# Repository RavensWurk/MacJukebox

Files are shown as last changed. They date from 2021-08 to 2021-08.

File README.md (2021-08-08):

Banner
This project is an effort to develop a jukebox expansion board for vintage Macintosh computers. 
It is meant to plug into the standard modem port on all compacts (and later desktops), and provide
USB storage, audio output via a headphone jack, and a control interface for the computers. 

It will support MP3 files at most common bitrates and sample frequencies. The Macintosh, being
unable to actually decode modern music files or output high qualithy sound, will act as the command
and control interface for this external board. Playlists can be made, viewing artists/albums/songs, 
controlling mixer levels and volume, and the external board will handle all the decoding of the file,
outputting it to the audio jack.

This repo is organised in to two parts, the firmware for the board itself under "Board", and the Macintosh
software side under "MacApp".

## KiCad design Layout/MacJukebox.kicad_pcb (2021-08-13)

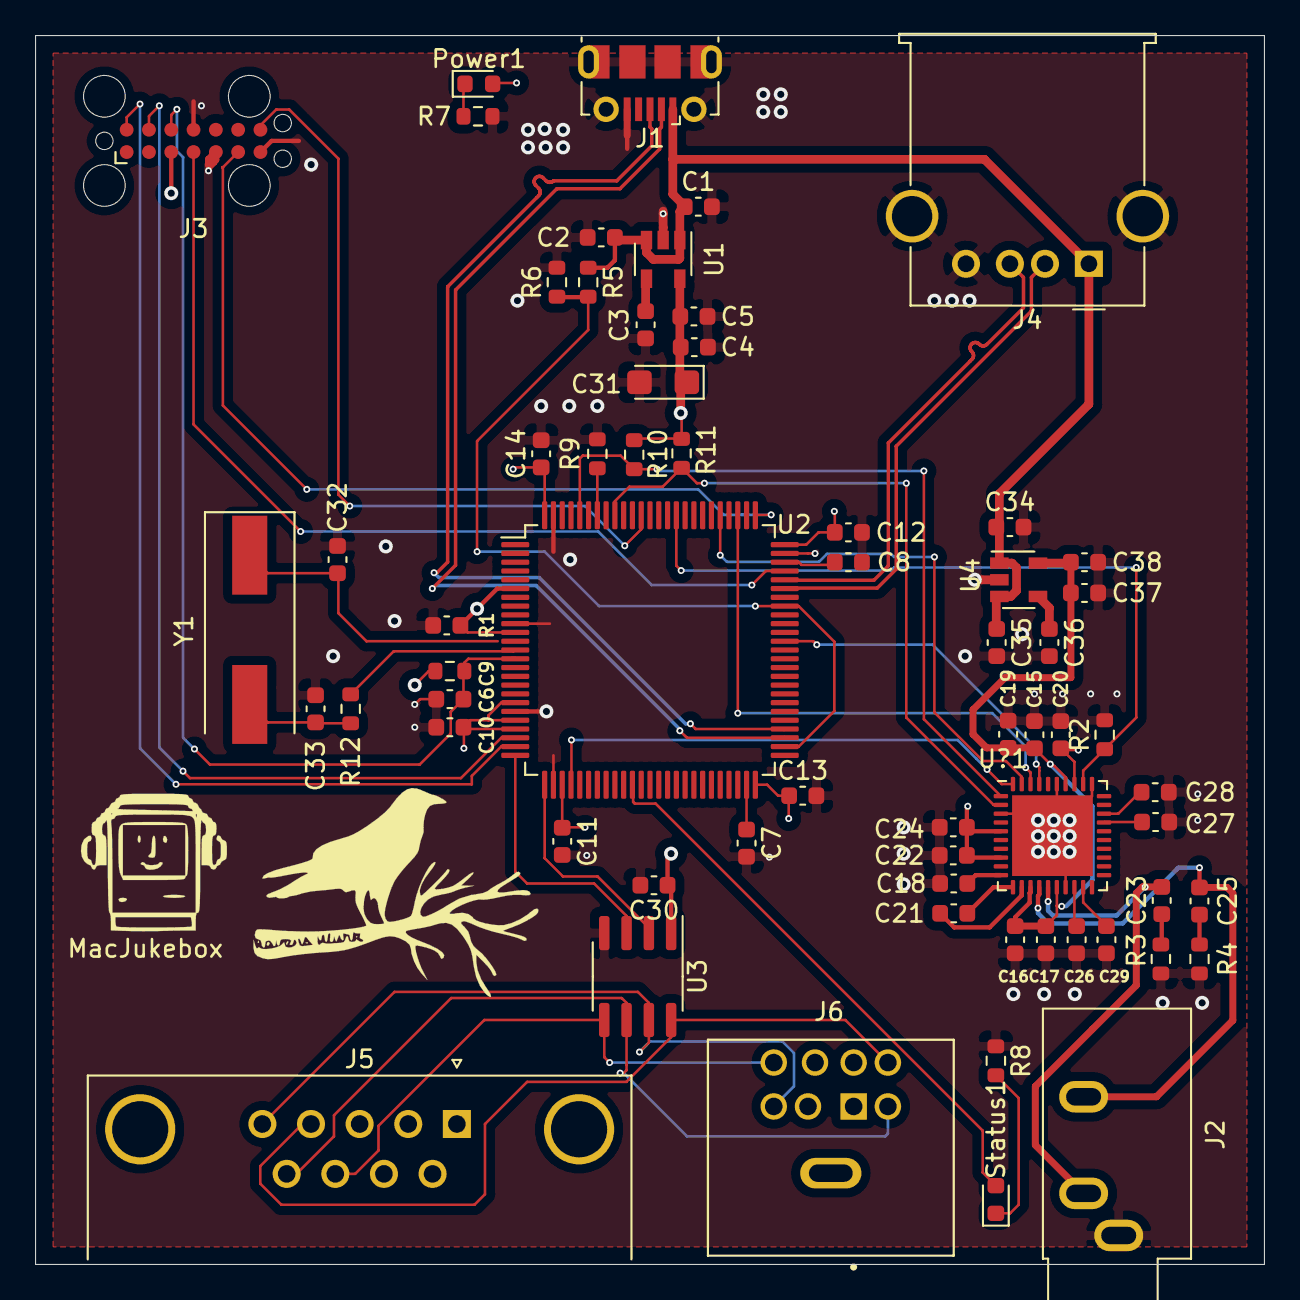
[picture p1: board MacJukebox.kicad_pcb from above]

Board: 4 copper layers, 70.0 x 70.0 mm, 64 parts (0 on the bottom side), 50 nets.

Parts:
C1, C4, C19, C22, C24, C30, C34, C37: 1uF; C_0603_1608Metric
C2, C5, C6, C9, C10, C11, C12, C13, C14, C15, C16, C17, C20, C35, C38: 100nF; C_0603_1608Metric
C3, C36: 10nF; C_0603_1608Metric
C7, C8: 2.2uF; C_0603_1608Metric
C18, C21, C26, C29: 1uF (X7R); C_0603_1608Metric
C23, C25: 22nF; C_0603_1608Metric
C27, C28: 150pF (C0G); C_0603_1608Metric
C31: 10uF; CP_EIA-3216-18_Kemet-A
C32, C33: 18pF; C_0603_1608Metric
J1: USB_B_Micro; USB_Micro-B_Molex-105017-0001
J2: AudioJack3; Jack_3.5mm_CUI_SJ1-3533NG_Horizontal
J3: Conn_ST_STDC14; Tag-Connect_TC2070-IDC-FP_2x07_P1.27mm_Vertical
J4: USB_A; USB_A_Molex_67643_Horizontal
J5: Mac 128/512; DSUB-9_Female_Horizontal_P2.77x2.84mm_EdgePinOffset4.94mm_H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
J6: Mini-DIN-8; CUI_MD-80S
Power1: RED LED; LED_0603_1608Metric
R1: 100K; R_0603_1608Metric
R2, R9: 10K; R_0603_1608Metric
R3, R4: 51; R_0603_1608Metric
R5: 1K; R_0603_1608Metric
R6: 2.4K; R_0603_1608Metric
R7, R8: 200; R_0603_1608Metric
R10, R11: 4.7K; R_0603_1608Metric
R12: 1.1K; R_0603_1608Metric
Status1: GREEN LED; LED_0603_1608Metric
U1: LD3985M33R_SOT23; SOT-23-5
U2: STM32F407VGTx; LQFP-100_14x14mm_P0.5mm
U3: MAX3488; SOIC-8_3.9x4.9mm_P1.27mm
U4: LD3985M25R_SOT23; SOT-23-5
U?1: CS43L22; QFN-40-1EP_6x6mm_P0.5mm_EP4.6x4.6mm
Y1: Crystal; Crystal_SMD_HC49-SD

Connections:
+2V5: C15.1, C16.1, C17.1, C19.1, C37.1, C38.1, U4.5, U?1.13, U?1.16, U?1.34
+3V3: C4.1, C5.1, C9.1, C10.1, C11.1, C12.1, C13.1, C14.1, C20.1, C22.1, C24.1, C30.1, C31.1, J3.3, Power1.2, R1.1, R10.1, R11.1, U1.5, U2.6, U2.11, U2.19, U2.21, U2.22, U2.28, U2.50, U2.75, U2.100, U3.1, U?1.5, U?1.8, U?1.33
+5V: C1.1, C2.1, C34.1, C35.1, J1.1, J4.1, R5.1, U1.1, U1.3, U4.1, U4.3
DI: U2.25, U3.3
GND: C1.2, C2.2, C3.2, C4.2, C5.2, C6.2, C7.2, C8.2, C9.2, C10.2, C11.2, C12.2, C13.2, C14.2, C15.2, C16.2, C17.2, C18.2, C19.2, C20.2, C22.2, C24.2, C26.2, C27.2, C28.2, C29.2, C30.2, C31.2, C32.1, C33.1, C34.2, C35.2, C36.2, C37.2, C38.2, J1.5, J1.6, J2.S, J3.5, J3.7, J3.11, J4.4, J4.5, R2.2, R3.1, R4.1, R6.2, R7.2, R8.1, R9.1, U1.2, U2.10, U2.20, U2.27, U2.74, U2.99, U3.4, U4.2, U?1.3, U?1.17, U?1.31, U?1.35, U?1.41
unnamed: C3.1, U1.4
unnamed: C7.1, U2.49
unnamed: C8.1, U2.73
unnamed: C18.1, U?1.10
unnamed: C21.1, U?1.11
unnamed: C21.2, U?1.12
unnamed: C23.1, R3.2
unnamed: C23.2, J2.T, U?1.15
unnamed: C25.1, R4.2
unnamed: C25.2, J2.R, U?1.14
unnamed: C26.1, U?1.18
unnamed: C27.1, U?1.27
unnamed: C28.1, U?1.28
unnamed: C29.1, U?1.19
unnamed: C33.2, R12.1, Y1.2
unnamed: C36.1, U4.4
unnamed: Power1.1, R7.1
unnamed: R8.2, Status1.1
unnamed: R9.2, U2.94
PA4: U2.29, U?1.40
PB6: R11.2, U2.92, U?1.2
PB9: R10.2, U2.96, U?1.1
PC7: U2.64, U?1.37
PC10: U2.78, U?1.38
PC12: U2.80, U?1.39
PD4: R2.1, U2.85, U?1.32
PH0: C32.2, U2.12, Y1.1
PH1: R12.2, U2.13
RO: U2.26, U3.2
RS422_RX+: J5.4, J6.6, U3.8
RS422_RX-: J5.5, J6.3, U3.7
RS422_TX+: J5.8, J6.8, U3.5
RS422_TX-: J5.9, J6.5, U3.6
RST: C6.1, J3.12, R1.2, U2.14
STATUS_LED: Status1.2, U2.36
SWCLK: J3.6, U2.76
SWDIO: J3.4, U2.72
SWO: J3.8, U2.89
USB_COMPUTER_D+: J1.3, U2.54
USB_COMPUTER_D-: J1.2, U2.53
USB_STORAGE_D+: J4.3, U2.71
USB_STORAGE_D-: J4.2, U2.70
VBUS_SENSE: R5.2, R6.1, U2.52, U2.68
VCP_RX: J3.13, U2.23
VCP_TX: J3.14, U2.24

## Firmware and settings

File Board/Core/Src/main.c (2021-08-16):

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
/* Includes ------------------------------------------------------------------*/
#include "main.h"
#include "cmsis_os.h"
#include "fatfs.h"
#include "usb_host.h"

/* USER CODE BEGIN Includes */
#include "codec.h"
#include "mp3player.h"
#include "uart_interface.h"
#include "pb_encode.h"
#include "parsers/filelist.pb.h"

/* USER CODE END Includes */

typedef StaticTask_t osStaticThreadDef_t;
I2C_HandleTypeDef hi2c1;

I2S_HandleTypeDef hi2s3;
DMA_HandleTypeDef hdma_spi3_tx;

SPI_HandleTypeDef hspi1;

UART_HandleTypeDef huart2;

/* Definitions for defaultTask */
osThreadId_t defaultTaskHandle;
uint32_t defaultTaskBuffer[ 1024 ];
osStaticThreadDef_t defaultTaskControlBlock;
const osThreadAttr_t defaultTask_attributes = {
  .name = "defaultTask",
  .stack_mem = &defaultTaskBuffer[0],
  .stack_size = sizeof(defaultTaskBuffer),
  .cb_mem = &defaultTaskControlBlock,
  .cb_size = sizeof(defaultTaskControlBlock),
  .priority = (osPriority_t) osPriorityNormal,
};
void SystemClock_Config(void);
static void MX_GPIO_Init(void);
static void MX_DMA_Init(void);
static void MX_I2C1_Init(void);
static void MX_I2S3_Init(void);
static void MX_SPI1_Init(void);
static void MX_USART2_UART_Init(void);
void StartDefaultTask(void *argument);

/* USER CODE BEGIN PFP */
bool writeListingToUART(pb_ostream_t *stream, const uint8_t *buf, size_t count);
/* USER CODE END PFP */

/**
  * @brief  The application entry point.
  * @retval int
  */
int main(void)
{
  /* MCU Configuration--------------------------------------------------------*/

  /* Reset of all peripherals, Initializes the Flash interface and the Systick. */
  HAL_Init();

  /* Configure the system clock */
  SystemClock_Config();

  /* Initialize all configured peripherals */
  MX_GPIO_Init();
  MX_DMA_Init();
  MX_I2C1_Init();
  MX_I2S3_Init();
  MX_SPI1_Init();
  MX_FATFS_Init();
  MX_USART2_UART_Init();
  /* Init scheduler */
  osKernelInitialize();

  /* USER CODE BEGIN RTOS_MUTEX */
  /* add mutexes, ... */
  /* USER CODE END RTOS_MUTEX */

  /* USER CODE BEGIN RTOS_SEMAPHORES */
  /* add semaphores, ... */
  /* USER CODE END RTOS_SEMAPHORES */

  /* USER CODE BEGIN RTOS_TIMERS */
  /* start timers, add new ones, ... */
  /* USER CODE END RTOS_TIMERS */

  /* USER CODE BEGIN RTOS_QUEUES */
  /* add queues, ... */
  /* USER CODE END RTOS_QUEUES */

  /* Create the thread(s) */
  /* creation of defaultTask */
  defaultTaskHandle = osThreadNew(StartDefaultTask, NULL, &defaultTask_attributes);

  /* USER CODE BEGIN RTOS_THREADS */
  /* add threads, ... */
  /* USER CODE END RTOS_THREADS */

  /* USER CODE BEGIN RTOS_EVENTS */
  /* add events, ... */
  /* USER CODE END RTOS_EVENTS */

  /* Start scheduler */
  osKernelStart();

  /* We should never get here as control is now taken by the scheduler */
  /* Infinite loop */
  /* USER CODE BEGIN WHILE */
  while (1)
  {
    /* USER CODE END WHILE */

    /* USER CODE BEGIN 3 */
  }
  /* USER CODE END 3 */
}

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
/* USER CODE BEGIN 4 */
struct MP3Player player;

bool encodeFileListing(pb_ostream_t *ostream, const pb_field_t *field, void * const *arg)
{
    const char *targetDir = (const char*)*arg;

    FILINFO info;
    DIR dir;
    FRESULT result = f_findfirst(&dir, &info, targetDir, "*.mp3");

    while (result == FR_OK && info.fname[0]) {
        FileListing_File file = {
            .Size = info.fsize
        };
        strcpy(file.Name, info.fname);

        pb_encode_tag_for_field(ostream, field);
        pb_encode_submessage(ostream, FileListing_File_fields, &file);
        result = f_findnext(&dir, &info);
    }

    f_closedir(&dir);

    return true;
}

void listFiles(void)
{
    pb_ostream_t uartStream = {
        writeListingToUART,
        NULL,
        SIZE_MAX,
        0
    };

    FileListing listing = FileListing_init_zero;
    listing.files.funcs.encode = encodeFileListing;
    listing.files.arg = "/";
    pb_encode(&uartStream, FileListing_fields, &listing);
}

bool writeListingToUART(pb_ostream_t *stream, const uint8_t *buf, size_t count)
{
    UartInterface_Write(&huart2, buf, count);

    return true;
}

void onCommand(Command* command)
{
    switch (command->id) {
        case Command_ID_PLAY_FILE:
            MP3PlayerPlayFile(&player, (const char*)command->data.bytes);
            break;
        case Command_ID_PAUSE:
            MP3PlayerPause(&player);
            break;
        case Command_ID_LIST_FILES:
            osThreadFlagsSet (defaultTaskHandle, 2);
            break;
        default:
            break;
    }
}

/* USER CODE END 4 */

/* USER CODE BEGIN Header_StartDefaultTask */
/**
  * @brief  Function implementing the defaultTask thread.
  * @param  argument: Not used
  * @retval None
  */
/* USER CODE END Header_StartDefaultTask */
void StartDefaultTask(void *argument)
{
  /* init code for USB_HOST */
  MX_USB_HOST_Init();
  /* USER CODE BEGIN 5 */
  struct Codec codec;

  codec.i2c = &hi2c1;
  codec.i2s = &hi2s3;

  CodecInit (CS43L22, &codec);

  osThreadFlagsWait(1, osFlagsWaitAny, 60000);

  f_mount (&USBHFatFS, USBHPath, 1);

  UartInterface_Init(&huart2);
  UartInterface_OnCommand(onCommand);

  player.task = defaultTaskHandle;
  player.codec = &codec;
  MP3PlayerInit(&player);

  /* Infinite loop */
  for(;;)
  {
      uint32_t flags = osThreadFlagsWait(2, osFlagsWaitAny, 60000);

      if (flags == 2)
      {
          listFiles();
      }
  }
  /* USER CODE END 5 */
}

 /**
  * @brief  Period elapsed callback in non blocking mode
  * @note   This function is called  when TIM7 interrupt took place, inside
  * HAL_TIM_IRQHandler(). It makes a direct call to HAL_IncTick() to increment
  * a global variable "uwTick" used as application time base.
  * @param  htim : TIM handle
  * @retval None
  */
void HAL_TIM_PeriodElapsedCallback(TIM_HandleTypeDef *htim)
{
  if (htim->Instance == TIM7) {
    HAL_IncTick();
  }
}

/**
  * @brief  This function is executed in case of error occurrence.
  * @retval None
  */
void Error_Handler(void)
{
  /* USER CODE BEGIN Error_Handler_Debug */
  /* User can add his own implementation to report the HAL error return state */
  __disable_irq();
  while (1)
  {
  }
  /* USER CODE END Error_Handler_Debug */
}

#ifdef  USE_FULL_ASSERT
/**
  * @brief  Reports the name of the source file and the source line number
  *         where the assert_param error has occurred.
  * @param  file: pointer to the source file name
  * @param  line: assert_param error line source number
  * @retval None
  */
void assert_failed(uint8_t *file, uint32_t line)
{
  /* USER CODE BEGIN 6 */
  /* User can add his own implementation to report the file name and line number,
     ex: printf("Wrong parameters value: file %s on line %d\r\n", file, line) */
  /* USER CODE END 6 */
}
#endif /* USE_FULL_ASSERT */

/************************ (C) COPYRIGHT STMicroelectronics *****END OF FILE****/

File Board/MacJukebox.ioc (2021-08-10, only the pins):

Mcu.UserName=STM32F407VGTx
PA0-WKUP.GPIO_Label=B1 [Blue PushButton]
PA0-WKUP.Signal=GPXTI0
PA10.GPIO_Label=OTG_FS_ID
PA10.Signal=USB_OTG_FS_ID
PA11.GPIO_Label=OTG_FS_DM
PA11.Signal=USB_OTG_FS_DM
PA12.GPIO_Label=OTG_FS_DP
PA12.Signal=USB_OTG_FS_DP
PA13.GPIO_Label=SWDIO
PA13.Signal=SYS_JTMS-SWDIO
PA14.GPIO_Label=SWCLK
PA14.Signal=SYS_JTCK-SWCLK
PA2.Signal=USART2_TX
PA3.Signal=USART2_RX
PA4.GPIO_Label=I2S3_WS [CS43L22_LRCK]
PA4.Signal=I2S3_WS
PA5.GPIO_Label=SPI1_SCK [LIS302DL_SCL/SPC]
PA5.Signal=SPI1_SCK
PA6.GPIO_Label=SPI1_MISO [LIS302DL_SDO]
PA6.Signal=SPI1_MISO
PA7.GPIO_Label=SPI1_MOSI [LIS302DL_SDA/SDI/SDO]
PA7.Signal=SPI1_MOSI
PA9.GPIO_Label=VBUS_FS
PA9.Signal=USB_OTG_FS_VBUS
PB10.GPIO_Label=CLK_IN [MP45DT02_CLK]
PB10.Signal=I2S2_CK
PB13.Signal=USB_OTG_HS_VBUS
PB14.Signal=USB_OTG_HS_DM
PB15.Signal=USB_OTG_HS_DP
PB2.GPIO_Label=BOOT1
PB2.Signal=GPIO_Input
PB3.GPIO_Label=SWO
PB3.Signal=SYS_JTDO-SWO
PB6.GPIO_Label=Audio_SCL [CS43L22_SCL]
PB6.Signal=I2C1_SCL
PB9.GPIO_Label=Audio_SDA [CS43L22_SDA]
PB9.Signal=I2C1_SDA
PC0.GPIO_Label=OTG_FS_PowerSwitchOn
PC0.Signal=GPIO_Output
PC10.GPIO_Label=I2S3_SCK [CS43L22_SCLK]
PC10.Signal=I2S3_CK
PC12.GPIO_Label=I2S3_SD [CS43L22_SDIN]
PC12.Signal=I2S3_SD
PC14-OSC32_IN.GPIO_Label=PC14-OSC32_IN
PC14-OSC32_IN.Signal=RCC_OSC32_IN
PC15-OSC32_OUT.GPIO_Label=PC15-OSC32_OUT
PC15-OSC32_OUT.Signal=RCC_OSC32_OUT
PC3.GPIO_Label=PDM_OUT [MP45DT02_DOUT]
PC3.Signal=I2S2_SD
PC7.GPIO_Label=I2S3_MCK [CS43L22_MCLK]
PC7.Signal=I2S3_MCK
PD12.GPIO_Label=LD4 [Green Led]
PD12.Signal=GPIO_Output
PD13.GPIO_Label=LD3 [Orange Led]
PD13.Signal=GPIO_Output
PD14.GPIO_Label=LD5 [Red Led]
PD14.Signal=GPIO_Output
PD15.GPIO_Label=LD6 [Blue Led]
PD15.Signal=GPIO_Output
PD4.GPIO_Label=Audio_RST [CS43L22_RESET]
PD4.Signal=GPIO_Output
PD5.GPIO_Label=OTG_FS_OverCurrent
PD5.Signal=GPIO_Input
PE1.GPIO_Label=MEMS_INT2 [LIS302DL_INT2]
PE1.Signal=GPXTI1
PE3.GPIO_Label=CS_I2C/SPI [LIS302DL_CS_I2C/SPI]
PE3.Signal=GPIO_Output
PH0-OSC_IN.GPIO_Label=PH0-OSC_IN
PH0-OSC_IN.Signal=RCC_OSC_IN
PH1-OSC_OUT.GPIO_Label=PH1-OSC_OUT
PH1-OSC_OUT.Signal=RCC_OSC_OUT

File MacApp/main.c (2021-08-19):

/*
     Copyright 2021 Ravenswurk.

     This file is part of MacJukebox.

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
     You should have received a copy of the GNU General Public License
     along with MacJukebox.  If not, see <http://www.gnu.org/licenses/>.
*/

#include <Quickdraw.h>
#include <Windows.h>
#include <Lists.h>
#include <Fonts.h>
#include <Resources.h>
#include <stdio.h>
#include <stdint.h>
#include <string.h>
#include <Devices.h>
#include <Serial.h>
#include <Sound.h>
#include <parsers/commands.h>
#include "serial.h"
#include "commands.h"
#include "filelist.pb.h"

static Rect initialWindowRect, nextWindowRect;

enum
{
    kMenuApple = 128,
    kMenuFile,
    kMenuOptions,
};

enum
{
    kItemAbout = 1,
    kItemQuit = 1,
    kModemPort = 1,
    kPrinterPort = 2
};

void ShowAboutBox()
{
    WindowRef w = GetNewWindow(129, NULL, (WindowPtr) - 1);
    MoveWindow(w,
        qd.screenBits.bounds.right/2 - w->portRect.right/2,
        qd.screenBits.bounds.bottom/2 - w->portRect.bottom/2,
        false);
    ShowWindow(w);
    SetPort(w);

    Handle h = GetResource('TEXT', 128);
    HLock(h);
    Rect r = w->portRect;
    InsetRect(&r, 10,10);
    TETextBox(*h, GetHandleSize(h), &r, teJustLeft);

    ReleaseResource(h);
    while(!Button())
        ;
    while(Button())
        ;
    FlushEvents(everyEvent, 0);
    DisposeWindow(w);
}


void DoMenuCommand(long menuCommand)
{
    Str255 str;
    WindowRef w;
    short menuID = menuCommand >> 16;
    short menuItem = menuCommand & 0xFFFF;
    if(menuID == kMenuApple)
    {
        if(menuItem == kItemAbout)
            ShowAboutBox();
        else
        {
            GetMenuItemText(GetMenu(128), menuItem, str);
            OpenDeskAcc(str);
        }
    }
    else if(menuID == kMenuFile)
    {
        switch(menuItem)
        {
            case kItemQuit:
                ExitToShell();
                break;
        }
    }
    else if (menuID == kMenuOptions)
    {
        if (menuItem == kModemPort) {
            CheckItem(GetMenu(kMenuOptions), kModemPort, true);
            CheckItem(GetMenu(kMenuOptions), kPrinterPort, false);
        } else if (menuItem == kPrinterPort) {
            CheckItem(GetMenu(kMenuOptions), kModemPort, false);
            CheckItem(GetMenu(kMenuOptions), kPrinterPort, true);
        }
    }

    HiliteMenu(0);
}

void Update(WindowRef w) {
    SetPort(w);
    BeginUpdate(w);
    EndUpdate(w);
}

void UpdateList(ListHandle list) {
    SetPort((*list)->port);
    LUpdate((*list)->port->visRgn, list);

    PenState penState;
    GetPenState(&penState);
    PenSize(1, 1);
    InsetRect(&(*list)->rView, -1, -1);
    FrameRect(&(*list)->rView);
    SetPenState(&penState);
}

void FileListCallback(FileListing_File *file, void* arg) {
    ListHandle list = (ListHandle)arg;
}

int main(int argc, char** argv) {
    InitGraf(&qd.thePort);
    InitFonts();
    InitWindows();
    InitMenus();
    TEInit();
    InitDialogs(NULL);

    SetMenuBar(GetNewMBar(128));
    AppendResMenu(GetMenu(128), 'DRVR');
    DrawMenuBar();

    WindowRef w = GetNewWindow(128, NULL, (WindowPtr) - 1);

    ControlRef playBtn = GetNewControl(128, w);
    ControlRef pauseBtn = GetNewControl(129, w);
    ControlRef skipBtn = GetNewControl(130, w);

    Rect listRect;
    Point p;
    SetRect(&listRect, 0, 0, 3, 0);
    SetPt(&p, 0, 0);

    Rect boundRect = w->portRect;
    boundRect.left += 10;
    boundRect.top += 10;
    boundRect.right -= 15;
    boundRect.bottom -= 50;

    ListHandle list = LNew(&boundRect, &listRect, p, 0, w,
           true, false, true, true);

    (**list).selFlags = 0;

    IOParam param = {0};
    SerialInit("\p.AOut", &param);
    ListFiles(&param, FileListCallback, &list);

    LAddRow(1, 1, list);
    SetPt(&p, 0, 0);
    LSetCell("David Bowie", strlen("David Bowie"), p, list);
    SetPt(&p, 1, 0);
    LSetCell("Ziggy", strlen("Ziggy"), p, list);
    LDraw(p, list);

    InitCursor();
    ShowWindow(w);
    SetPort(w);

    while(true) {
        EventRecord e;
        WindowRef win;

        SystemTask();
        if(GetNextEvent(everyEvent, &e))
        {
            switch(e.what)
            {
                case keyDown:
                    if(e.modifiers & cmdKey)
                    {
                        DoMenuCommand(MenuKey(e.message & charCodeMask));
                    }
                    break;
                case mouseDown:
                    switch(FindWindow(e.where, &win))
                    {
                        case inGoAway:
                            if(TrackGoAway(win, e.where))
                                DisposeWindow(win);
                            break;
                        case inDrag:
                            DragWindow(win, e.where, &qd.screenBits.bounds);
                            break;
                        case inMenuBar:
                            DoMenuCommand( MenuSelect(e.where) );
                            break;
                        case inContent:
                            SelectWindow(win);

                            Point point = e.where;
                            GlobalToLocal(&point);
                            ControlRef cntrl;
                            if (FindControl(point, win, &cntrl) != 0) {
                                TrackControl(cntrl, point, NULL);
                            }

                            LClick(point, e.modifiers, list);

                            break;
                        case inSysWindow: {
                            SystemClick(&e, win);
                            break;
                        }
                    }
                    break;
                case updateEvt:
                    Update((WindowRef)e.message);
                    UpdateList(list);
                    break;
            }
        }
    }

    return 0;
}

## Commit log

2021-03-23 Bump I2S clock to 125MHz to fix error rate. Enable USART2
    [MacJukebox.ioc, main.c]
2021-03-23 Use own decoder loop to switch files at runtime
2021-08-03 Move to board folder, start mac app
2021-08-05 Fix endianness of length, set mac compatible baud
    [main.c]
2021-08-07 Rework Makefile, add pause command
    [main.c]
2021-08-09 Start adding board schem and layout
    [MacJukebox.kicad_pcb, MacJukebox.sch]
2021-08-09 Add USB and LED sections
    [MacJukebox.kicad_pcb, MacJukebox.sch]
2021-08-10 Enable USB device, start laying out board
    [MacJukebox.kicad_pcb, MacJukebox.sch]
2021-08-11 Finish first layout of board
    [MacJukebox.kicad_pcb, MacJukebox.sch]
2021-08-13 Final corrections, submitted board to fab house
    [MacJukebox.kicad_pcb, MacJukebox.sch]

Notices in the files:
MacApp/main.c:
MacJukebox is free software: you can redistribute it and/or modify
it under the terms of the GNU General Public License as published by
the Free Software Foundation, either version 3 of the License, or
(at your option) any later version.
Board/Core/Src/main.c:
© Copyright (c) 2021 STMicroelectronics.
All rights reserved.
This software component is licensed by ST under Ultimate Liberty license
